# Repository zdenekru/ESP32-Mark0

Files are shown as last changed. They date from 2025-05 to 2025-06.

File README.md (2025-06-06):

# ESP32 Mark0

**ESP32 Mark0** is a powerful and not-so-compact IoT development project based on the ESP32-WROOM-32 microcontroller. This project showcases both hardware and firmware design, with a focus on wireless communication, embedded control, and a simple web dashboard interface.

---

## 🚀 Project Overview

ESP32 Mark0 is designed to:

- Prototype embedded systems using Wi-Fi and basic web interface
- Interface with sensors and other potential peripherals
- Provide a physical platform for experimenting with ESP32 capabilities
- Demonstrate firmware/web integration between Arduino and Python/HTML

> Developed step-by-step with the help of OpenAI's ChatGPT — from schematic to code.

---

## 🔧 Features

- **ESP32-WROOM-32** module
- USB-C interface with **CH340** USB-to-Serial bridge
- Reset and Boot buttons
- Status LED
- Breadboard-compatible pinout
- Custom KiCad PCB (Rev0 and Rev1)
- Firmware written in **Arduino IDE**
- Python and HTML files edited in **VS Code**
- Manufactured via [JLCPCB.com](https://jlcpcb.com)

---

## 🗂️ Repository Structure

```
ESP32-Mark0/
├── 25Zak001 ESP32 Mark0-backups/ # Backup versions and old files
├── CodeESP32/ESP32_Mark0_Github_ready/ # Arduino firmware
├── CodePython/ # Python scripts and dashboard HTML
├── Manufacturing Files Rev0/ # Rev0 Gerbers and fab files
├── Manufacturing Files Rev1/ # Final Rev1 files for production
├── .kicad_ # KiCad project files (Rev0 and Rev1)
├── .gitignore
├── .gitattributes
├── README.md
├── fp-info-cache
├── qrCode.kicad_sym
└── 25Zak001 ESP32 Mark0.step # 3D model of the board
```

---

## 🛠️ Development Environment

### Prerequisites

- **Arduino IDE** with ESP32 board support
- USB-C cable
- **CH340** USB driver
- **KiCad** (for editing hardware files)
- **VS Code** (for editing HTML/Python dashboard files)

---

## ⚙️ Uploading Firmware

Upload the sketch via Arduino IDE after selecting the correct board and port:

- **Board**: ESP32 Dev Module
- **Upload Speed**: 115200
- **Port**: (as assigned by your system)

---

## 🌐 Web Dashboard

The web dashboard (in `CodePython/`) includes a lightweight HTML interface that interacts with the ESP32 over Wi-Fi. Customize this dashboard for sensor readouts, toggles, or control logic.

---

## 🏭 Manufacturing

Both **Rev0** and **Rev1** were designed in **KiCad** and manufactured via **[JLCPCB](https://jlcpcb.com)**. All Gerber, BOM, and position files are provided in the respective manufacturing folders.

---

## 🤖 AI-Assisted Engineering

This project was co-developed with **ChatGPT**, assisting in:

- ESP32 firmware debugging and optimization
- PCB design decisions and validation
- HTML/Python dashboard integration
- Repository structure and documentation

---

## 📜 License

MIT License – see `LICENSE` file.

---

Made with ☕, perseverance, and ChatGPT.

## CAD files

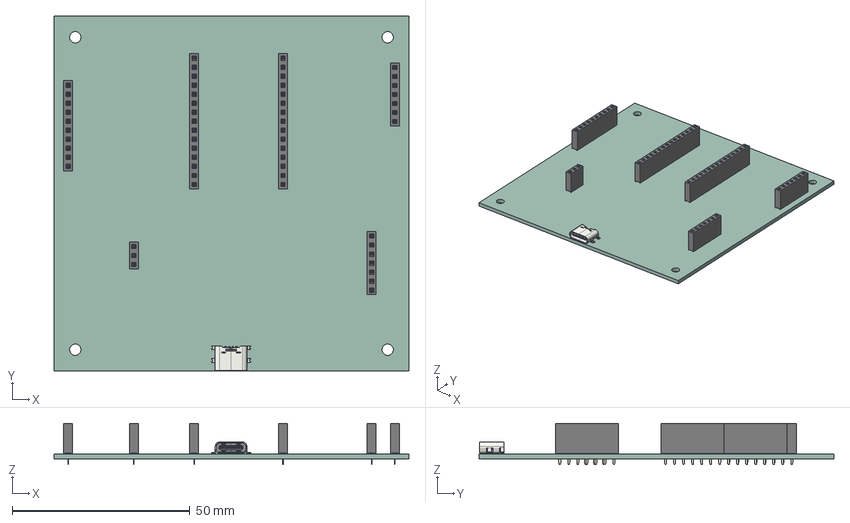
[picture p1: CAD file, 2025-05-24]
25Zak001 ESP32 Mark0.step
100.0 x 100.0 x 11.6 mm
PinSocket_1x07_P2.54mm_Vertical x 2
PinSocket_1x15_P2.54mm_Vertical x 2
PinSocket_1x10_P2.54mm_Vertical
PinSocket_1x03_P2.54mm_Vertical
USB_C_Receptacle_GCT_USB4135-GF-A_6P_TopMnt_Horizontal
25Zak001 ESP32 Mark0_PCB

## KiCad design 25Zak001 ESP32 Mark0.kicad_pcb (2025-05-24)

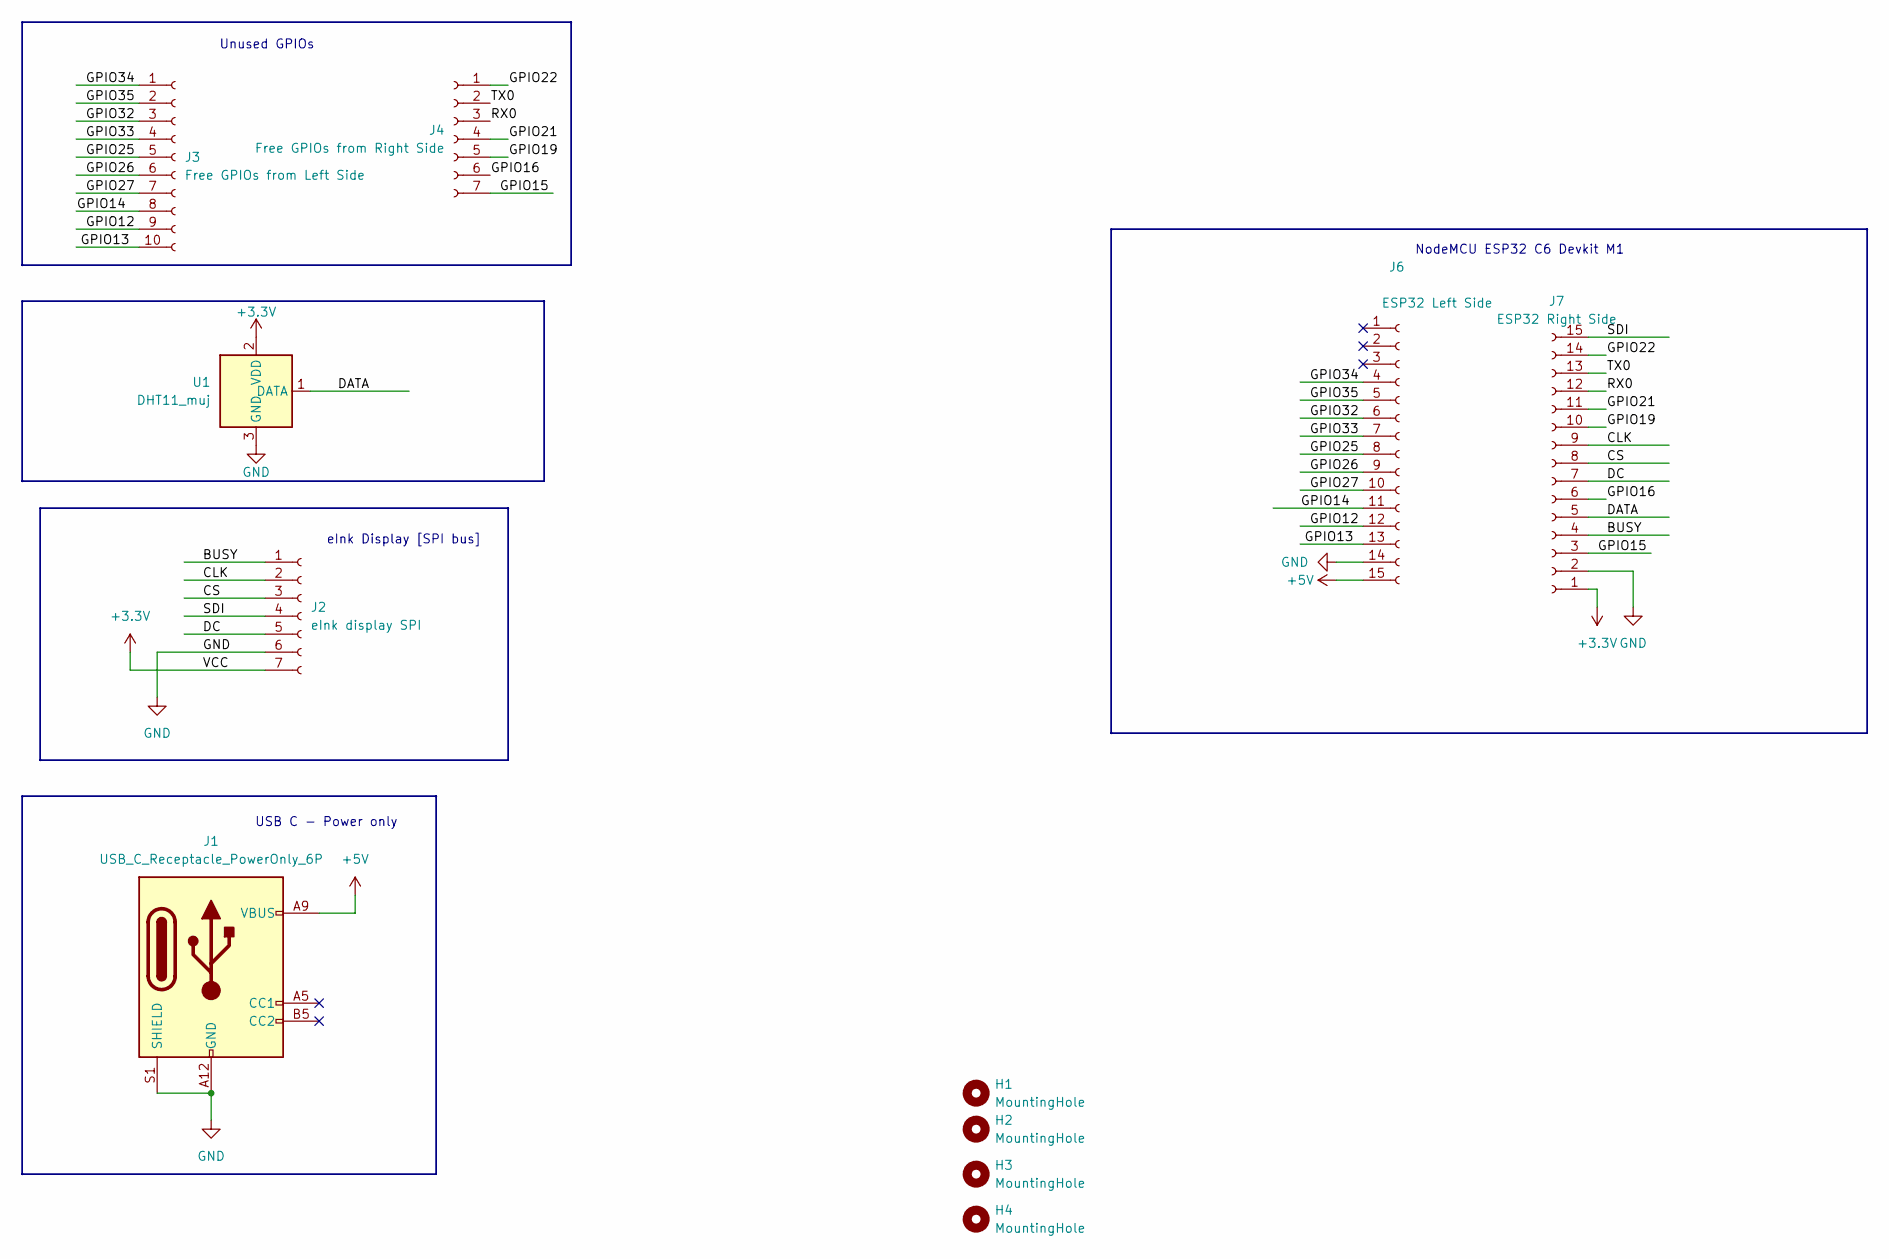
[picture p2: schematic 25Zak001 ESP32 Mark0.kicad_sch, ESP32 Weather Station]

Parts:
H1, H2, H3, H4: MountingHole; MountingHole_3.2mm_M3_ISO14580_Pad_TopBottom
J1: USB_C_Receptacle_PowerOnly_6P; USB_C_Receptacle_GCT_USB4135-GF-A_6P_TopMnt_Horizontal
J2: eInk display SPI; PinSocket_1x07_P2.54mm_Vertical
J3: Free GPIOs from Left Side; PinSocket_1x10_P2.54mm_Vertical
J4: Free GPIOs from Right Side; PinSocket_1x07_P2.54mm_Vertical
J6: ESP32 Left Side; PinSocket_1x15_P2.54mm_Vertical
J7: ESP32 Right Side; PinSocket_1x15_P2.54mm_Vertical
U1: DHT11_muj; PinSocket_1x03_P2.54mm_Vertical

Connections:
+3.3V: J2.7, J7.1, U1.2 (VDD)
+5V: J1.A9 (VBUS), J1.B9 (VBUS), J6.15
/BUSY: J2.1, J7.4
/CLK: J2.2, J7.9
/CS: J2.3, J7.8
/DATA: J7.5, U1.1 (DATA)
/DC: J2.5, J7.7
/GPIO12: J3.9, J6.12
/GPIO13: J3.10, J6.13
/GPIO14: J3.8, J6.11
/GPIO15: J4.7, J7.3
/GPIO16: J4.6, J7.6
/GPIO19: J4.5, J7.10
/GPIO21: J4.4, J7.11
/GPIO22: J4.1, J7.14
/GPIO25: J3.5, J6.8
/GPIO26: J3.6, J6.9
/GPIO27: J3.7, J6.10
/GPIO32: J3.3, J6.6
/GPIO33: J3.4, J6.7
/GPIO34: J3.1, J6.4
/GPIO35: J3.2, J6.5
/RX0: J4.3, J7.12
/SDI: J2.4, J7.15
/TX0: J4.2, J7.13
GND: J1.A12 (GND), J1.B12 (GND), J1.S1 (SHIELD), J2.6, J6.14, J7.2, U1.3 (GND)

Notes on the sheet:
USB C - Power only
eInk Display [SPI bus]
NodeMCU ESP32 C6 Devkit M1
Unused GPIOs

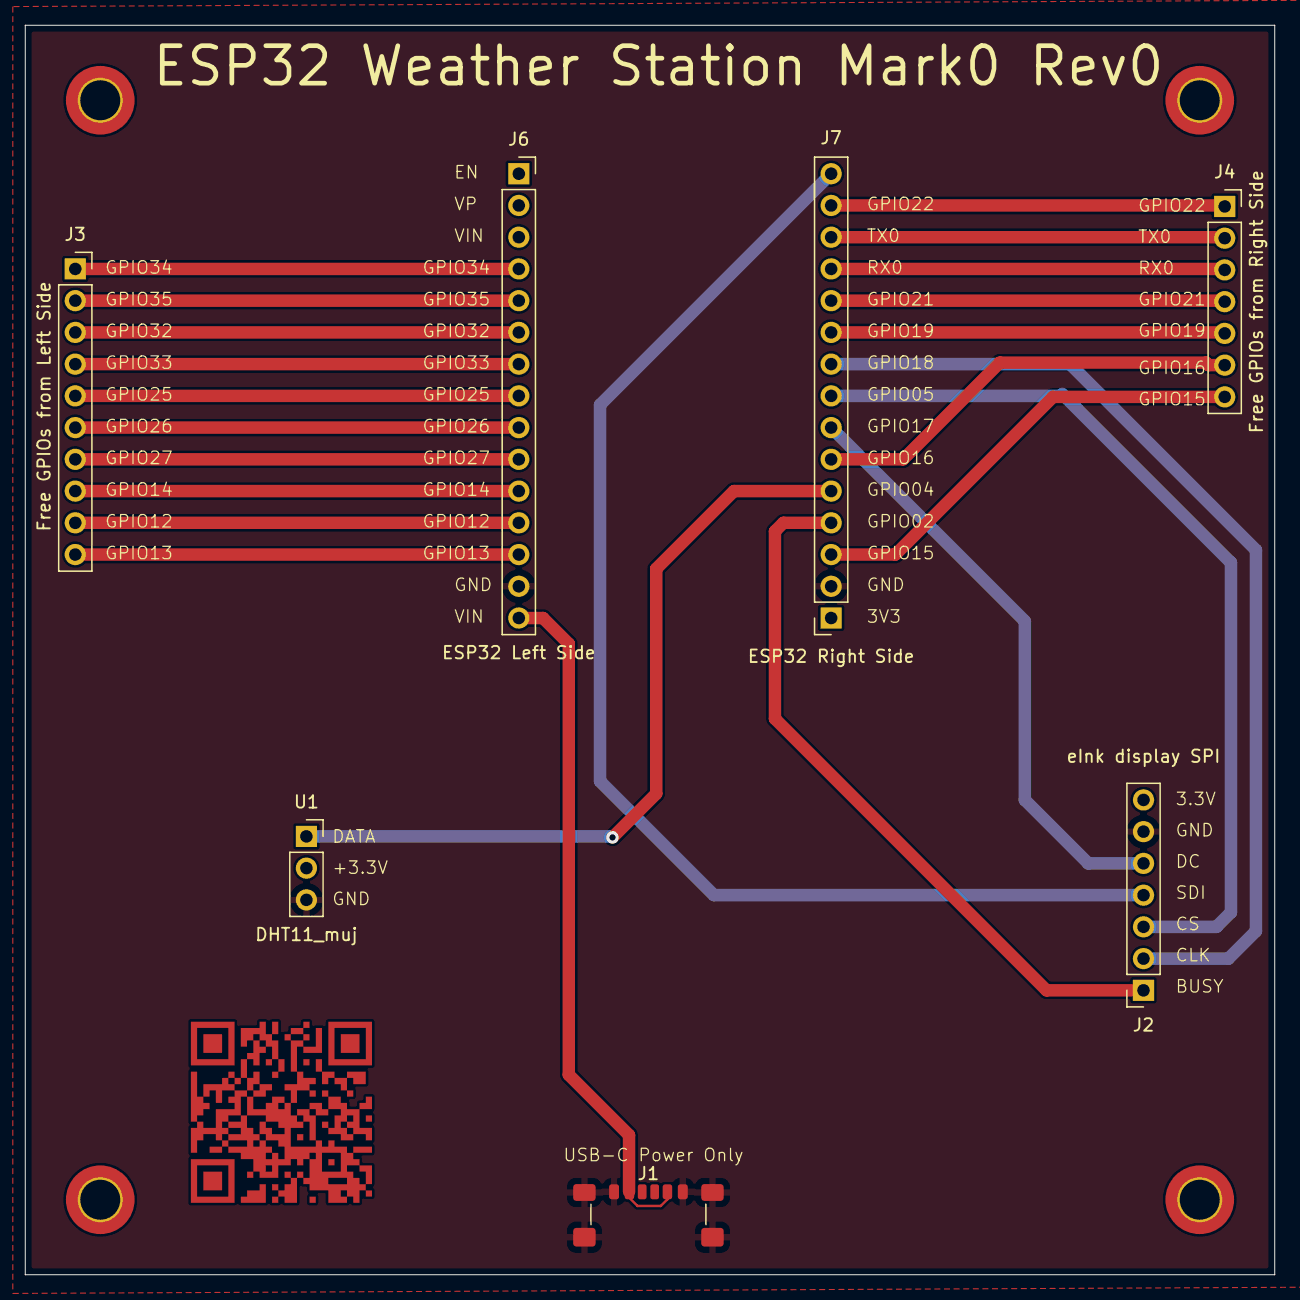
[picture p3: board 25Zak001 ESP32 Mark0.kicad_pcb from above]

Board: 2 copper layers, 100.0 x 100.0 mm, 12 parts (0 on the bottom side), 26 nets.

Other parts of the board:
QR*****: QR_kod_esp32_mod0

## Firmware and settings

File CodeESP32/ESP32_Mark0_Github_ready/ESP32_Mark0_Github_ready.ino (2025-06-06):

/*************************************************************
  ESP32 + DHT11 + Blynk + 1.54" e-Ink Display (Heltec)
  Shows Temp & Humidity on Blynk app and e-Ink every 2 minutes
 *************************************************************/

#define BLYNK_PRINT Serial

#include "secrets.h"
#include <WiFi.h>
#include <WiFiClient.h>
#include <BlynkSimpleEsp32.h>
#include <DHT.h>
#include <GxEPD2_BW.h>
#include <Adafruit_GFX.h>
#include <Fonts/FreeMonoBold9pt7b.h>
#include <ArduinoOTA.h>
#include <HTTPClient.h>        // 🆕 For HTTP requests
#include <ArduinoJson.h>       // 🆕 For JSON parsing

// ==== WiFi Credentials ====
char ssid[] = WIFI_SSID;
char pass[] = WIFI_PASSWORD;

// ===== OpenWeatherMap setup ====
const char* city = "Brno";
const char* countryCode = "CZ";
const char* weatherApiKey = WEATHER_API_KEY; // 🆕 Insert your real key

// 🆕 Struct to hold weather info
struct WeatherData {
  float temp;
  float feels_like;
  String description;
};

// 🌍 Global weather object (must come AFTER the struct)
WeatherData globalWeather;

// ======= Timing Variables for the loop part =======

unsigned long lastBlynkTime = 0;
unsigned long lastWeatherTime = 0;
unsigned long lastEInkUpdate = 0;
unsigned long lastFlaskUpdate = 0;

const unsigned long BLYNK_INTERVAL = 5 * 60 * 1000;     // 5 minutes
const unsigned long WEATHER_INTERVAL = 5 * 60 * 1000;   // 5 minutes
const unsigned long EINK_INTERVAL = 3 * 60 * 1000;      // 3 minutes
const unsigned long FLASK_INTERVAL = 30 * 1000;         // 30 seconds

// 🆕 Fetch weather from OpenWeatherMap
WeatherData fetchWeather() {
  WeatherData data = {0, 0, "Načítám..."};

  String url = "http://api.openweathermap.org/data/2.5/weather?q=" + String(city) + "," + String(countryCode) + "&units=metric&appid=" + weatherApiKey + "&lang=cz";
  HTTPClient http;
  http.begin(url);

  int httpCode = http.GET();
  if (httpCode == 200) {
    String payload = http.getString();

    StaticJsonDocument<1024> doc;
    deserializeJson(doc, payload);

    data.temp = doc["main"]["temp"];
    data.feels_like = doc["main"]["feels_like"];
    data.description = doc["weather"][0]["description"].as<String>();
  } else {
    Serial.println("❌ Failed to fetch weather");
  }

  http.end();
  return data;
}


// ==== DHT Setup ====
#define DHTPIN 4          // GPIO4 for DHT11
#define DHTTYPE DHT11
DHT dht(DHTPIN, DHTTYPE);

// ==== E-Ink Setup (Heltec 1.54", 200x200) ====
#define EPD_CS    5   // Chip Select
#define EPD_DC    17  // Data/Command
#define EPD_BUSY  2   // Busy (Changed from GPIO 4)
#define EPD_CLK   18  // Clock (SPI SCK)
#define EPD_MOSI  23  // Data Input (SPI SDI)
#define EPD_RST   -1  // Not used (-1 means it's not connected)
GxEPD2_BW<GxEPD2_154_D67, GxEPD2_154_D67::HEIGHT> display(GxEPD2_154_D67(EPD_CS, EPD_DC, EPD_RST, EPD_BUSY));

// ==== Blynk Timer ====
BlynkTimer timer;

// ✅ Function to get current time as HH:MM:SS string
String getCurrentTime() {
  struct tm timeinfo;
  if (!getLocalTime(&timeinfo)) return "--:--:--";
  char buf[9];
  strftime(buf, sizeof(buf), "%H:%M:%S", &timeinfo);
  return String(buf);
}

// Funkce na vypocet uptimu

String getUptime() {
  unsigned long uptimeMillis = millis();
  unsigned long hours = uptimeMillis / 3600000;
  unsigned long minutes = (uptimeMillis % 3600000) / 60000;
  unsigned long seconds = (uptimeMillis % 60000) / 1000;
  
  char uptimeString[9]; // HH:MM:SS format
  snprintf(uptimeString, sizeof(uptimeString), "%02lu:%02lu:%02lu", hours, minutes, seconds);
  
  return String(uptimeString);
}

// 🧪 Send data to local Flask server

void sendToLocalServer(float temp, float hum, WeatherData weather, String uptime, String currentTime) {
  HTTPClient http;
  http.begin(LOCAL_SERVER_URL);
  http.addHeader("Content-Type", "application/json");

  StaticJsonDocument<512> doc;
  doc["uptime"] = uptime;
  doc["timestamp"] = currentTime;
  doc["temp_inside"] = temp;
  doc["humidity"] = hum;
  doc["temp_outside"] = weather.temp;
  doc["feels_like"] = weather.feels_like;
  doc["description"] = weather.description;

  String jsonPayload;
  serializeJson(doc, jsonPayload);

  int httpResponseCode = http.POST(jsonPayload);
  if (httpResponseCode > 0) {
    Serial.println("📡 Local server response: " + String(httpResponseCode));
  } else {
    Serial.println("❌ Failed to connect to local server");
  }

  http.end();
}

// ==== Function: Read sensor and update Blynk + e-Ink ====
void sendSensor()
{
  float h = dht.readHumidity();
  float t = dht.readTemperature();

  if (isnan(h) || isnan(t)) {
    Serial.println("❌ Failed to read from DHT sensor!");
    return;
  }

  // 🆕 Fetch weather BEFORE using its values
  WeatherData weather = fetchWeather();

  // Uptime
  String uptime = getUptime();

  // 🕒 Print time and uptime
  String currentTime = getCurrentTime();
  Serial.println("⏰ Čas: " + currentTime);
  Serial.println("⏰ Uptime: " + uptime); // Log uptime

  // 🌡️ Print indoor temp & humidity
  Serial.printf("✅ Uvnitř: %.1f°C, Vlhkost: %.1f%%\n", t, h);

  // 🌤️ Print weather data
  Serial.printf("🌡️  Venku: %.1f°C (Pocitová: %.1f°C)\n", weather.temp, weather.feels_like);
  Serial.print("🌥️  Popis: ");
  Serial.println(weather.description);

  String location = String(city) + ", " + countryCode;

  // ✅ Send to Blynk
  Blynk.virtualWrite(V1, uptime);         // Send uptime to Virtual Pin V1
  Blynk.virtualWrite(V5, h);
  Blynk.virtualWrite(V6, t);
  Blynk.virtualWrite(V7, weather.temp);
  Blynk.virtualWrite(V8, weather.feels_like);
  Blynk.virtualWrite(V9, weather.description);

  // ✅ Show on e-Ink
  display.setFullWindow();
  display.firstPage();
  do {
    display.fillScreen(GxEPD_WHITE);
    display.setTextColor(GxEPD_BLACK);
    display.setFont(&FreeMonoBold9pt7b);

    display.setCursor(10, 20);
    display.print("Uptime: ");
    display.print(uptime);

    display.setCursor(10, 40);
    display.print("Cas: ");
    display.print(getCurrentTime());

    display.setCursor(10, 70);
    display.print(location);

    display.setCursor(10, 100);
    display.printf("%.1f°C (pocit %.1f°C)", weather.temp, weather.feels_like); 

    display.setCursor(10, 130);
    display.print(weather.description);

    display.setCursor(20, 160);
    display.print("Teplota: ");
    display.print(t, 1);
    display.print(" °C");

    display.setCursor(20, 190);
    display.print("Vlhkost: ");
    display.print(h, 1);
    display.print(" %");
  } while (display.nextPage());

  Serial.println("🖥️  E-Ink display updated.");

  // 🧪 Send to local Flask dashboard
  sendToLocalServer(t, h, weather, uptime, currentTime);
}


void setup()
{
  Serial.begin(115200);
  Serial.println("Booting...");

  // Init Blynk + WiFi
  Blynk.begin(BLYNK_AUTH_TOKEN, ssid, pass);

  // Init DHT sensor
  dht.begin();

  // Init e-Ink display
  display.init();
  display.setRotation(3);

  // ✅ Setup NTP time sync
  // Timezone config (Central Europe, with DST auto-switch)
  setenv("TZ", "CET-1CEST,M3.5.0/2,M10.5.0/3", 1);
  tzset();

  // Start NTP sync
  configTime(3600, 3600, "pool.ntp.org", "time.nist.gov");

  struct tm timeinfo;
  while (!getLocalTime(&timeinfo)) {
    Serial.println("⏳ Waiting for time...");
    delay(1000);
  }
  Serial.println("🕒 Time synchronized");

  // Start OTA
  ArduinoOTA.setHostname("ESP32-DHT-EINK");
  ArduinoOTA.begin();
  Serial.println("🔄 OTA Ready!");

}

void loop() {
  unsigned long now = millis();

  Blynk.run();
  ArduinoOTA.handle();
  timer.run();  // Still running for backward compatibility (e.g., display update)

  // Fetch weather every 5 minutes
  if (now - lastWeatherTime >= WEATHER_INTERVAL) {
    globalWeather = fetchWeather();
    lastWeatherTime = now;
  }

  // Send Blynk data every 5 minutes
  if (now - lastBlynkTime >= BLYNK_INTERVAL) {
    float h = dht.readHumidity();
    float t = dht.readTemperature();
    String uptime = getUptime();

    if (!isnan(h) && !isnan(t)) {
      Blynk.virtualWrite(V1, uptime);
      Blynk.virtualWrite(V5, h);
      Blynk.virtualWrite(V6, t);
      Blynk.virtualWrite(V7, globalWeather.temp);
      Blynk.virtualWrite(V8, globalWeather.feels_like);
      Blynk.virtualWrite(V9, globalWeather.description);
    }

    lastBlynkTime = now;
  }

  // Update e-Ink display every 3 minutes
  if (now - lastEInkUpdate >= EINK_INTERVAL) {
    sendSensor();  // This updates display + sends to local Flask too
    lastEInkUpdate = now;
  }

  // Send data to local Flask every 30 seconds
  if (now - lastFlaskUpdate >= FLASK_INTERVAL) {
    float h = dht.readHumidity();
    float t = dht.readTemperature();
    String uptime = getUptime();
    String currentTime = getCurrentTime();

    if (!isnan(h) && !isnan(t)) {
      sendToLocalServer(t, h, globalWeather, uptime, currentTime);
    }

    lastFlaskUpdate = now;
  }
}

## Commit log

2025-03-15 Prvni nahradni projektu
    [25Zak001 ESP32 Mark0.kicad_pcb, 25Zak001 ESP32 Mark0.kicad_sch]
2025-03-15 Pridano USB C
    [25Zak001 ESP32 Mark0.kicad_pcb, 25Zak001 ESP32 Mark0.kicad_sch]
2025-03-16 Nova verze
    [25Zak001 ESP32 Mark0.kicad_pcb, 25Zak001 ESP32 Mark0.kicad_sch]
2025-03-16 Dokonceni, plno chyb, nutno opravit
    [25Zak001 ESP32 Mark0.kicad_pcb, 25Zak001 ESP32 Mark0.kicad_sch]
2025-05-10 Fairly Big Update
    - completly reworked ESP32 devkit
    - different sensor
    - all unused GPIOs are now available via sockets
    [25Zak001 ESP32 Mark0.kicad_pcb]
2025-05-24 Rev1 created for PCB
    Because Rev0 is virutally unusable in current state.
    [25Zak001 ESP32 Mark0 Rev1-B_Cu.gbr, 25Zak001 ESP32 Mark0 Rev1-B_Mask.gbr, 25Zak001 ESP32 Mark0 Rev1-B_Paste.gbr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]
2025-06-06 Fixed communication
    humidity is showing, temperature not, I have to work on that
    [ESP32_Mark0_Github_ready.ino]
2025-06-06 Update app.py
    temperature fixed
2025-06-06 Fixing arduinoIDE file
